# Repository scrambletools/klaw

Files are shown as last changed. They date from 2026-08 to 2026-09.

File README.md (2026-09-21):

# KLAW - 34-key split keyboard

KLAW is a compact **34-key split keyboard with LEDs, OLED, buzzer and
encoder**. It is designed as one reversible PCB that serves both halves -
components on the back face make the right half, components on the front face
make the left half. One board design: the same gerber files can be used for
both halves, with separate BOM and CPL files per half. Every component can be
machine-assembled, but you may want to hand-assemble the MCU and OLED modules.
The latest hardware revision is rev 2.

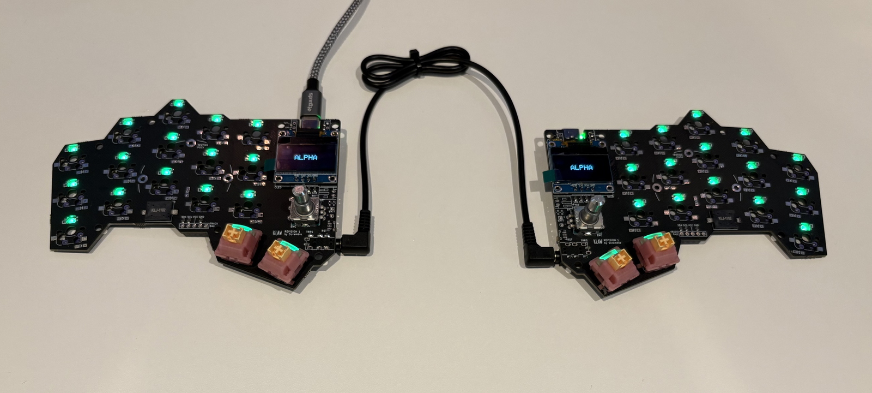
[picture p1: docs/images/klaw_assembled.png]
KLAW - assembled pair


Below are renders of the right half:

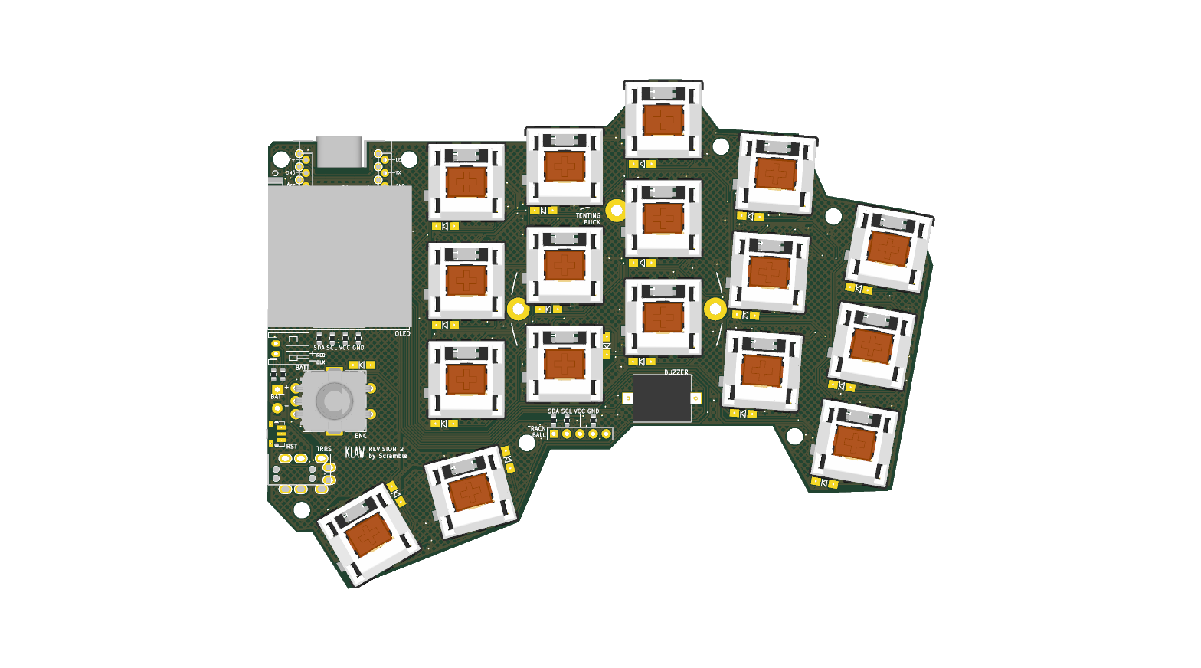
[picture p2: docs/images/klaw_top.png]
KLAW PCB - keycap side

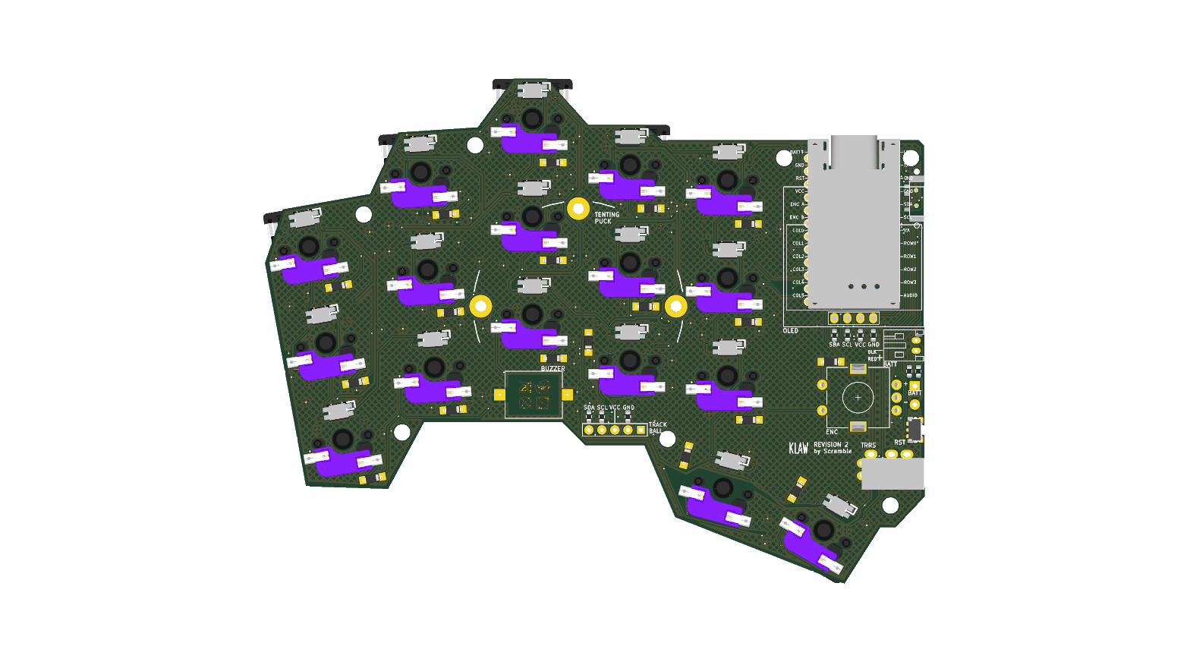
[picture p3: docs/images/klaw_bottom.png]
KLAW PCB - component side


## Features

- **34 keys** (17 per half), column-staggered, MX-style switches
- **Hot-swap sockets** (Kailh CPG151101S11-compatible) - no switch soldering
- **Per-key RGB** - SK6812MINI-EA LEDs, reverse-mounted to glow through the board (machine-assemblable)
- **Wired or wireless** - TRRS between halves, or Bluetooth with a
  nice!nano-compatible controller (socketed, Pro Micro pinout); battery
  connector and power switch on board (unpopulated in the wired-first default)
- **Rotary encoder** (EC11) per half - volume knob or anything you map to it
- **0.96″ SSD1306 OLED** per half
- **Piezo buzzer**, reset button, and optional
  [splitkb tenting puck](https://splitkb.com/products/tenting-puck) mounting
- **Optional trackball** level-converter header (unpopulated by default)
- **Configuration by placement** - the OLED mapping, trackball routing, and
  battery-polarity links are 0603 0R resistors, placed per side by the
  assembly service; nothing to bridge by hand

## Repository layout

| Path | Contents |
|---|---|
| `pcb/klaw_2/` | KiCad 10 project - schematic, board, project library with LCSC sourcing fields and 3D models |
| `fab/` | JLCPCB production files - gerbers, drills, BOM, placement (see `fab/README.md`) |
| `bom/` | Per-half build BOMs (`bom_left.csv`, `bom_right.csv`) with LCSC part numbers |
| - | Firmware (QMK/Vial) lives in [scrambletools/klaw-firmware](https://github.com/scrambletools/klaw-firmware) |

The case is designed in Plasticity and maintained outside this repository.

## Building one

**1. Order the PCBs.** Both halves use the **same board** - upload
`fab/klaw_2-gerbers.zip` to [JLCPCB](https://jlcpcb.com) (2-layer, 1.6 mm). For
machine assembly place **two orders with the same gerbers**: the right half
assembles on the **Bottom** side (`fab/right-half/`), the left half on the
**Top** side (`fab/left-half/`). Each order is double-sided and covers everything
solderable - see `fab/README.md` for the exact flow and placement-review checklist.

**2. No soldering required** - the assembly orders cover everything solderable:
diodes, factory-reversed per-key RGB LEDs (SK6812MINI-EA), hot-swap sockets,
TRRS, buzzer, reset switch, encoder, and each side's 0R configuration resistors
(double-sided assembly: the buzzer and encoder mount on the keycap face, every
other machine-placed part on the component face).
Mount-face tables, part numbers, prices, and per-half quantities are in `bom/`.

**3. Add your own** MX-style switches (hot-swap, no soldering), a
nice!nano-compatible controller (socket it - the MCU mounts on the **bottom**,
components facing the PCB, as marked on the silkscreen), a 4-pin I²C SSD1306
OLED module, and keycaps. For a wireless build, additionally fit the power
switch (`C431540`), JST battery connector (`C173752`), and a 301230-or-similar
LiPo - those three positions are DNP in the wired-first default, but their
polarity-selection resistors are already placed correctly per side.

**4. Firmware.** Flash the KLAW firmware (QMK/Vial) from
[scrambletools/klaw-firmware](https://github.com/scrambletools/klaw-firmware).

The KiCad project embeds datasheet links, LCSC part numbers, and last-checked
stock/pricing on every schematic symbol, so `kicad-cli sch export bom` always
gives you a current shopping list.

## Credits & license

KLAW is a derivative of the [KLOR](https://github.com/GEIGEIGEIST/KLOR)
keyboard by GEIGEIGEIST - the layout, reversible-footprint approach, and much
of the PCB heritage come from that project. Licensed under **GPL-3.0**, same
as KLOR; see `LICENSE.md`. The Cherry MX switch 3D model comes from the
[kiswitch keyswitch-kicad-library](https://github.com/kiswitch/keyswitch-kicad-library)
(MIT / CC-BY-SA 4.0); the nRF52840 SuperMini controller model comes from
[shnaps/garden36](https://github.com/shnaps/garden36) (MIT).

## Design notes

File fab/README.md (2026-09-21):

# KLAW - Fabrication & Assembly Files

Production files for **JLCPCB** (PCB fab + PCBA assembly). One reversible board
serves both keyboard halves - same gerbers, two assembly configurations:

- **Right half** = keycap side is the PCB **front**; machine-assembled parts go
  on the **Bottom** (back) face
- **Left half** = mirror image; machine-assembled parts go on the **Top**
  (front) face

- **Board size:** ~128 × 97 mm
- **Layers:** 2 (F.Cu / B.Cu), 1.6 mm
- **Assembly per board:** 8 BOM line items, 65 placements, **double-sided**
  (JLC Standard assembly). Component face: 18 diodes, 17 reverse-mount
  SK6812MINI-EA LEDs, 17 hotswap sockets, TRRS jack, reset switch. Keycap
  face: buzzer, encoder.
- **Not assembled:** power switch + JST connector (DNP, wired-first config),
  MCU + OLED (user-supplied, socketed), MX switches + keycaps (plug-in).
  Nothing on the board needs a soldering iron after assembly.
- **Orientation:** the component face is the keyboard's underside - mostly
  Bottom for the right-half order, mostly Top for the left-half (each order is
  double-sided). Backwards-looking bottom silkscreen text in the raw 2D gerber
  view is correct (viewer convention), and Bottom-layer parts (e.g. the right
  build's diodes) legitimately look mirrored/reversed when compared against a
  top view - judge polarity only by comparing a part against the silkscreen
  arrow in the SAME view, never across views. The two builds' rotations are
  twins by construction (shared-pad parts: bottom = (540 - top) mod 360).
- LED placement rows use synthetic designators (`LED1`…`LED21`, numbered by key)
  since the LEDs share footprints with the switches; JLCPCB matches them by
  coordinates. The LED bodies protrude ~0.2 mm past the far face - JLC may add
  an assembly-fixture charge for this.

> These files are committed from the design in `../pcb/klaw_2/`; don't hand-edit
> them. Regenerate with `kicad-cli` after design changes.

## How to order a pair

Place **two PCBA orders**, both using the **same** `klaw_2-gerbers.zip`:

| Order | Gerbers | BOM | CPL | Assembly side |
|---|---|---|---|---|
| Right halves | `klaw_2-gerbers.zip` | `right-half/klaw_2-right-BOM.csv` | `right-half/klaw_2-right-CPL.csv` | both (mostly Bottom) |
| Left halves | `klaw_2-gerbers.zip` | `left-half/klaw_2-left-BOM.csv` | `left-half/klaw_2-left-CPL.csv` | both (mostly Top) |

JLCPCB's minimum order is 5 boards / 2 assembled, so a typical pair order is:
2× assembled right + 2× assembled left, with spare bare boards left over.

> **Check the placement preview.** Rotation conventions vary between tools, so
> in JLCPCB's "parts placement" review verify each part sits on its pads -
> diode polarity against the silkscreen arrows - and nudge rotations there if
> needed. JLC's DFM review also flags misalignments. **Exception - LEDs:** the
> preview renders from JLC's library model, which is 180° off from the OPSCO
> datasheet for C5378731, so correctly-ordered LEDs will LOOK 180° rotated in
> the preview. Do NOT "fix" them there; verify with the bare-board diode test
> on arrival instead (see postmortem below).
> Known rotation rules baked into these CPLs (re-apply if regenerating):
> hotswap sockets (HS*) **and LEDs (LED*)** carry a +180° intrinsic tape offset
> on both layers. Bottom-layer rows additionally need +180° over the naive
> (360-θ) mirror ONLY for parts whose footprint has shared/same pads on both
> faces (diodes, TRRS, encoder); parts with per-face mirrored pad patterns
> (LEDs, sockets, buzzer, reset switch) absorb the flip in the footprint and
> use the plain mirror (plus intrinsic offset where noted). Current calibrated
> LED values: Top rows 180° (176° for the rotated key), Bottom rows 0° (4°).
>
> **Run-1 postmortem (2026-09):** both halves shipped with every LED rotated
> 180°. The footprint's original silkscreen marked the wrong pad, so the JLC
> preview calibration AND physical inspection both "confirmed" the reversed
> placement - and JLC's library model for C5378731 numbers the pins 180° from
> the OPSCO datasheet (datasheet: 1 GND, 2 DIN, 3 VDD, 4 DOUT). A reversed
> SK6812MINI-EA clamps the 5 V rail through its body diode (~0.4 V in diode
> mode, ~0.7 V under load) and the board plays dead, while ohms mode reads a
> healthy-looking ~7 kΩ (meter voltage below the junction threshold).
> **Acceptance test for every batch, bare board, before fitting a controller:**
> diode mode across VCC↔GND - **+ on VCC must read open**; ~0.4 V there means
> reversed LEDs (+ on GND showing ~0.5 V is the normal body diode). The
> silkscreen GND-pad mark is fixed as of run 2; parts must match it.

## Files

| File | Purpose |
|---|---|
| `klaw_2-gerbers.zip` | Upload to JLCPCB for PCB fab (copper, mask, paste, silk, edge, drills) - shared by both orders |
| `right-half/` | Assembly BOM + CPL for the right half (Top side) |
| `left-half/` | Assembly BOM + CPL for the left half (Bottom side) |
| `klaw_2-*.gbr`, `klaw_2-*.drl` | The individual layers inside the zip, for inspection |

## Ordering notes

- **Wired-first configuration:** the power switch (PSW1) and JST battery
  connector (BT1) are DNP - the wireless parts return in a future battery
  variant.
- LED (`LED1`…) and socket (`HS1`…) placement rows use synthetic designators -
  they share footprints with the switches; JLCPCB matches by coordinates.
- The 0R configuration resistors (`JP*`) select each build's configuration: each
  order places only its build's subset (keycap-face OLED/trackball set +
  component-face JST-polarity pair), so OLED pin mapping and battery polarity
  are correct per side with no hand bridging. Do NOT add the other side's JP
  rows to an order - the JST pairs are mutually exclusive.
- Confirm C41430893 (sockets) and the THT parts exist in JLCPCB's parts library
  at order time, or pre-order them into your JLC parts account.
- The buzzer (`C201047`) runs low on stock; check availability before ordering.

## Regenerating

```sh
cd pcb/klaw_2
kicad-cli pcb export gerbers -o ../../fab/ \
  --layers F.Cu,B.Cu,F.Mask,B.Mask,F.Paste,B.Paste,F.Silkscreen,B.Silkscreen,Edge.Cuts \
  --no-protel-ext klaw_2.kicad_pcb
kicad-cli pcb export drill --excellon-separate-th -o ../../fab/ klaw_2.kicad_pcb
kicad-cli pcb export pos --format csv --units mm --side both -o pos.csv klaw_2.kicad_pcb
# right CPL: Assembly=JLC refs, Layer=Top, as exported
# left CPL:  same refs/coords, Layer=Bottom, rotation = (360 - rot) % 360
```

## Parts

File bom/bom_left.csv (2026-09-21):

Part | Designators | Qty | LCSC Part # | Source | Mount Face | Notes
klaw reversible PCB (klaw_2) | PCB | 1 | - | JLCPCB fab | - | Same gerbers both halves; left build components on FRONT face, right build on BACK face
1N4148W diode SOD-123 | D1-D10,D12-D16,D18,D20,D21 | 18 | C81598 | LCSC/JLC-assembled | Front | Orientation per silkscreen arrow; through-plated pads
SK6812MINI-EA RGB LED (reverse-mount) | SW1-SW10,SW12-SW16,SW20,SW21 | 17 | C5378731 | LCSC/JLC-assembled | Front | Factory-reversed butterfly legs; lens shines through to keycap side
MX hotswap socket (Kailh CPG151101S11 compat) | SW1-SW10,SW12-SW16,SW20,SW21 | 17 | C41430893 | LCSC/JLC-assembled | Front | JLC-assembled; HanElectricity clone, footprint-identical to Kailh
MSK12C02 power slide switch | PSW1 | 0 | C431540 | DNP (wired config) | Front | Re-enable for battery variant; component side (opposite encoder)
Alps SKRTLAE010 reset switch | RSW1 | 1 | C110293 | LCSC | Front | JLC-assembled on component side (opposite encoder); side-actuated at board edge
JST PH 2-pin battery connector (S2B-PH-K-S) | BT1 | 0 | C173752 | DNP (wired config) | Front | Re-enable for battery variant; mounts on component side
TRRS jack PJ-320A-4P (MJ-4PP-9 compatible THT) | J1 | 1 | C18185602 | LCSC | Front | JLC-assembled on component side; body sits 1.75mm off-center vs keycap-face mount - check case aperture; verify slot fit on first order
Piezo buzzer KLJ-1102 | BZ1 | 1 | C201047 | LCSC | Back | HAND-SOLDER on keycap side; AST1109MLTRQ is a drop-in substitute; low stock
EC11 rotary encoder w/ switch (Alps EC11N1525404) | SW18 | 1 | C470748 | LCSC | Back | HAND-SOLDER from keycap side; 20mm D-cut shaft - D-bore push-on or set-screw knob; 30 det/15 pulse
SSD1306 128x64 OLED module 0.96in 4-pin I2C | OLED1 | 1 | - | User-supplied | Back | Keycap side, covers MCU pins; tape the back
Controller nice!nano-compatible (nRF52840, Pro Micro pinout) | U1 | 1 | - | User-supplied | Front | Socketed on component side, components facing PCB
MX switches | SW1-SW21 keys | 17 | - | User-supplied | Back | Insert from keycap side into sockets
0R configuration resistor 0603 | JP5-JP8,JP19-JP21,JP22,JP24 | 9 | C21189 | LCSC/JLC-assembled | mixed (see fab CPL) | Replaces solder jumpers; per-side subset sets OLED mapping + JST polarity; other side's set stays empty
Trackball level converter | J3 | 0 | - | DNP | - | Marked DNP in schematic

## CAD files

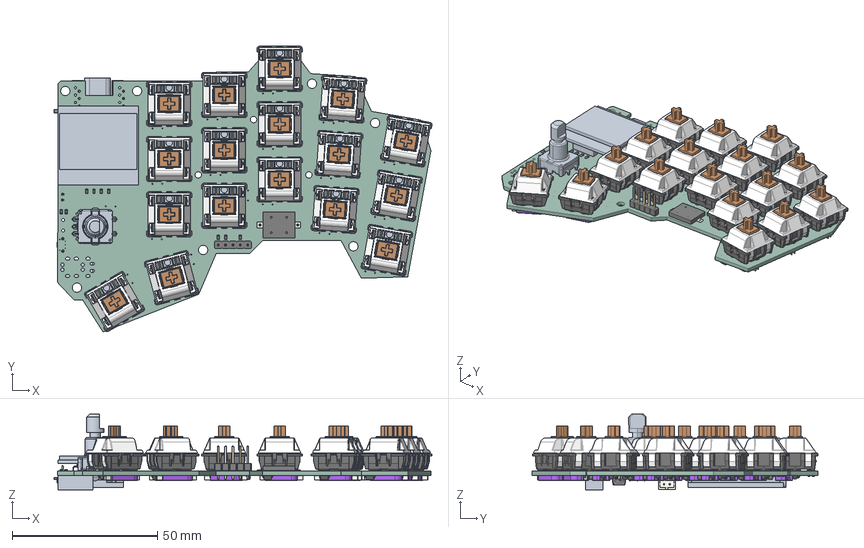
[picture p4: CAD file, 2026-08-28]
pcb/klaw_2/klaw_2.step
130.2 x 98.5 x 26.1 mm
R_0603_1608Metric x 18
SW_Cherry_MX_PCB_cp x 17
零件2 x 17
D_SOD-123 x 18
Buzzer_Mallory_AST1109MLTRQ
JST_S2B_PH_K
KEY-SMD_L4.6-W3.4-H3.4
SW-SMD_3P-L6.6-W2.7-LS7.8-P1.50
PinHeader_1x05_P254mm_Vertical
klaw_1_PCB

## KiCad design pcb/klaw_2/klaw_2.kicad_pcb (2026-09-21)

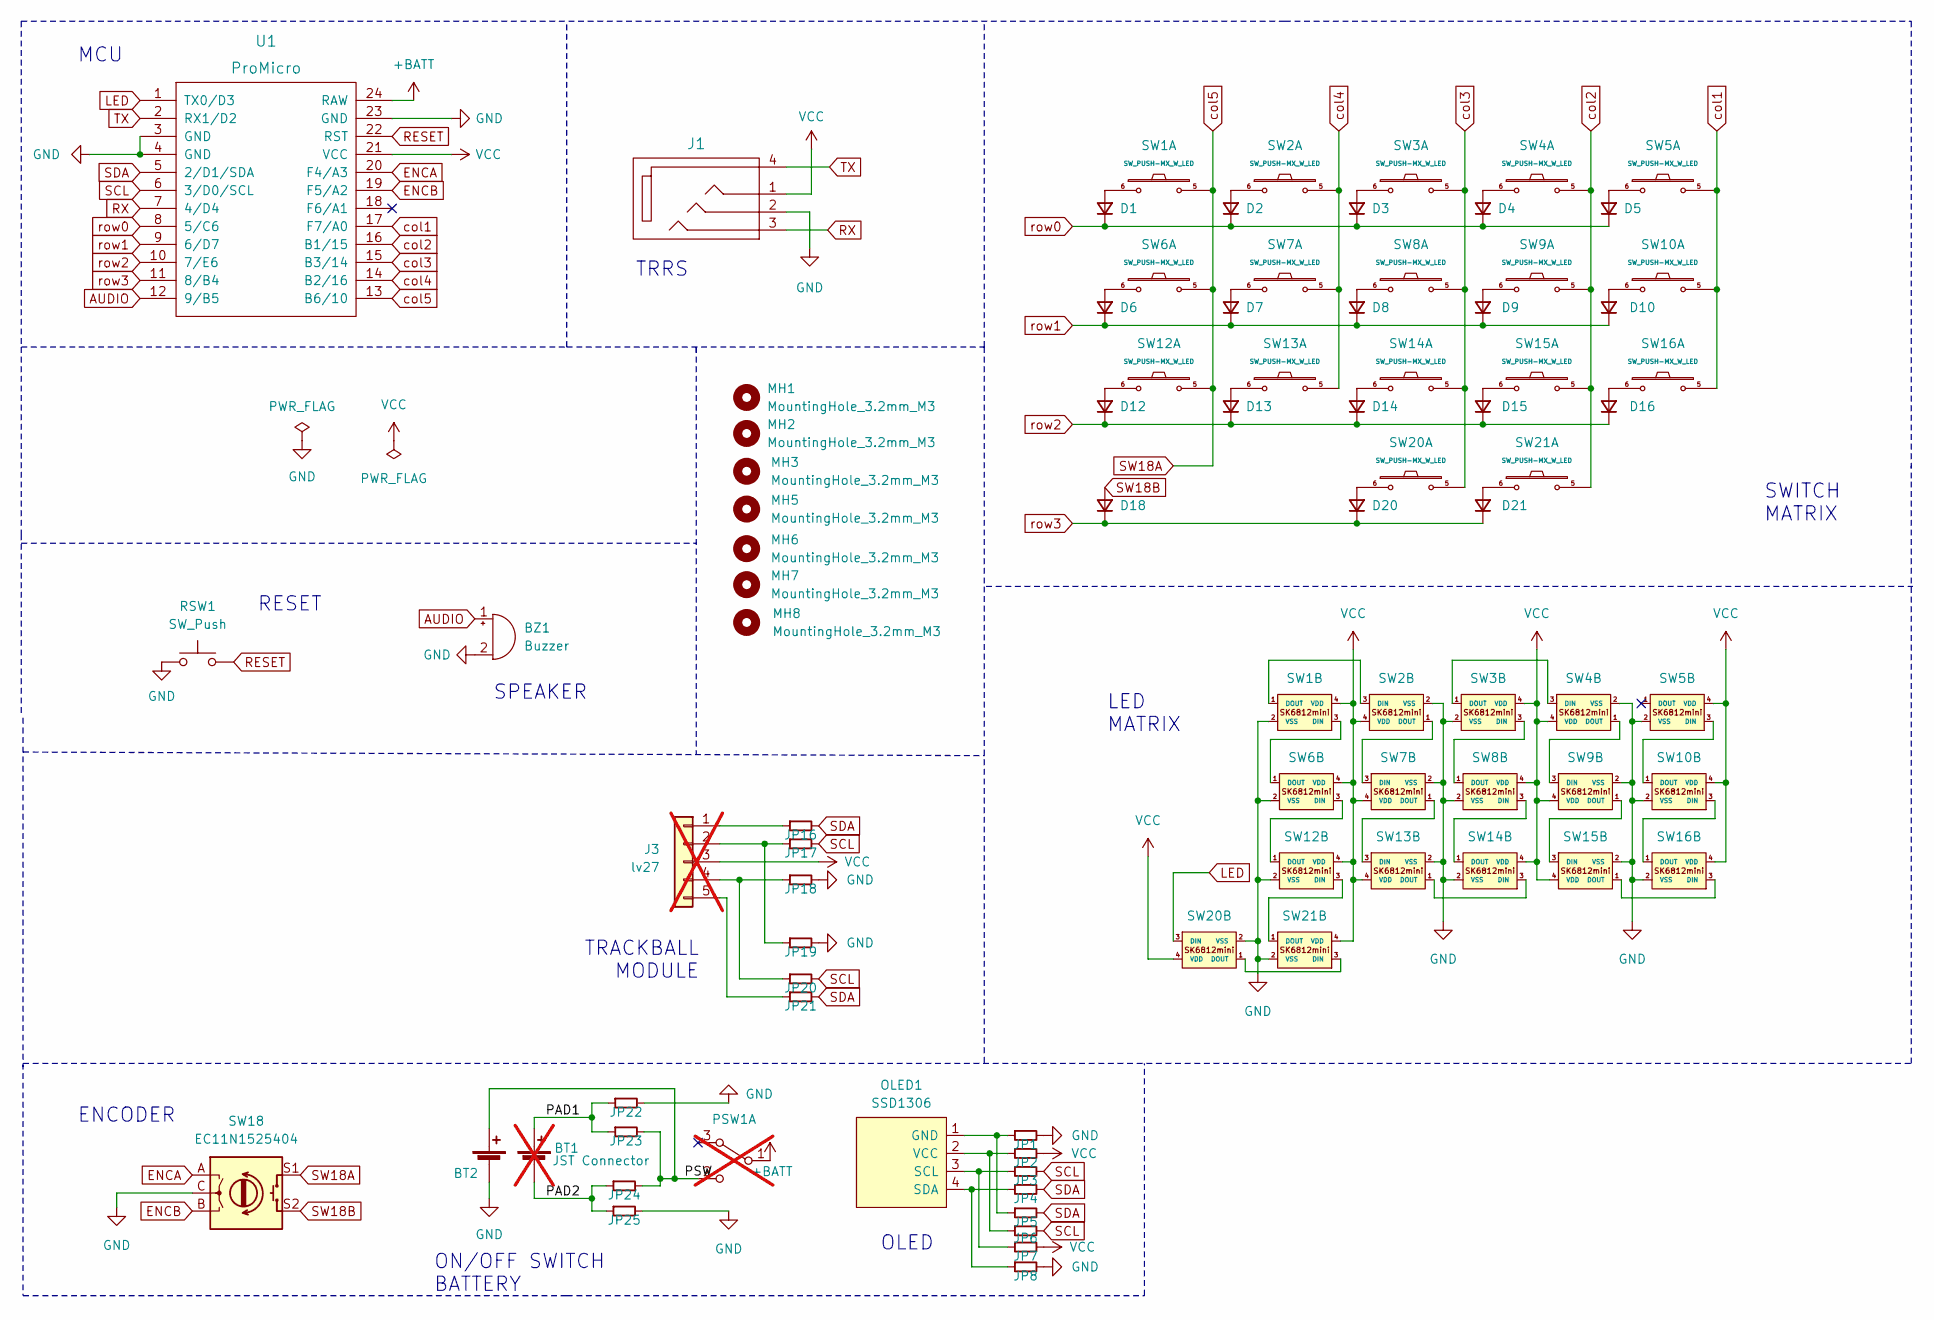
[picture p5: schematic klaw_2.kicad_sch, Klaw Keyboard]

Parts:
BT1: JST Connector; JST_PH_reversible; LCSC C173752; not fitted
BT2: Battery_Cell; custombatteryconnector_small
BZ1: Buzzer; Buzzer_Mallory_AST1109MLTRQ_reversible; LCSC C201047
D1, D2, D3, D4, D5, D6, D7, D8, D9, D10, D12, D13, D14, D15, D16, D18, D20, D21: 1N4148W; Diode_SOD123; LCSC C81598
J1: PJ-320A-4P; MJ-4PP-9; MPN PJ-320A-4P; LCSC C18185602
J3: lv27; lvc27_onlyInput; not fitted
JP1, JP2, JP3, JP4, JP5, JP6, JP7, JP8, JP16, JP17, JP18, JP19, JP20, JP21, JP22, JP23, JP24, JP25: 0R; R_0603_1608Metric; MPN 0603WAF0000T5E; LCSC C21189
MH1, MH2, MH3, MH5, MH6, MH7, MH8: MountingHole_3.2mm_M3
OLED1: SSD1306; SSD1306_128x64OLED
PSW1: SW_DPDT_x2; MSK12C02_reversible; LCSC C431540; not fitted
RSW1: SW_Push; SW_Push_1P1T-MP_NO_Horizontal_Alps_SKRTLAE010_both_sides; LCSC C110293
SW1, SW2, SW3, SW4, SW5, SW6, SW7, SW8, SW9, SW10, SW12, SW13, SW14, SW15, SW16, SW20, SW21: SW_PUSH-MX_W_LED; SK6812MINI_and_cherry; MPN SK6812MINI-EA; LCSC C5378731
SW18: EC11N1525404; RotaryEncoder_Alps_EC11E-Switch_Vertical_H20mm-keebio_modif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; MPN EC11N1525404; LCSC C470748
U1: ProMicro

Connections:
+BATT: PSW1.1 (B), U1.24 (RAW)
/PAD1: BT1.1 (+), JP22.1, JP23.1
/PAD2: BT1.2 (-), JP24.1, JP25.1
/PSW: BT2.1 (+), JP23.2, JP24.2, PSW1.2 (C)
AUDIO: BZ1.1 (-), U1.12 (9/B5)
ENCA: SW18.A, U1.20 (F4/A3)
ENCB: SW18.B, U1.19 (F5/A2)
GND: BT2.2 (-), BZ1.2 (+), J1.2, JP1.2, JP8.2, JP18.2, JP19.2, JP22.2, JP25.2, RSW1.1, SW1.2 (VSS), SW2.2 (VSS), SW3.2 (VSS), SW4.2 (VSS), SW5.2 (VSS), SW6.2 (VSS), SW7.2 (VSS), SW8.2 (VSS), SW9.2 (VSS), SW10.2 (VSS), SW12.2 (VSS), SW13.2 (VSS), SW14.2 (VSS), SW15.2 (VSS), SW16.2 (VSS), SW18.C, SW20.2 (VSS), SW21.2 (VSS), U1.3 (GND), U1.4 (GND), U1.23 (GND)
LED: SW20.3 (DIN), U1.1 (TX0/D3)
unnamed: D1.2 (A), SW1.6
unnamed: D2.2 (A), SW2.6
unnamed: D3.2 (A), SW3.6
unnamed: D4.2 (A), SW4.6
unnamed: D5.2 (A), SW5.6
unnamed: D6.2 (A), SW6.6
unnamed: D7.2 (A), SW7.6
unnamed: D8.2 (A), SW8.6
unnamed: D9.2 (A), SW9.6
unnamed: D10.2 (A), SW10.6
unnamed: D12.2 (A), SW12.6
unnamed: D13.2 (A), SW13.6
unnamed: D14.2 (A), SW14.6
unnamed: D15.2 (A), SW15.6
unnamed: D16.2 (A), SW16.6
unnamed: D20.2 (A), SW20.6
unnamed: D21.2 (A), SW21.6
unnamed: J3.1, JP16.1
unnamed: J3.2, JP17.1, JP19.1
unnamed: J3.4, JP18.1, JP20.1
unnamed: J3.5, JP21.1
unnamed: JP1.1, JP5.1, OLED1.1 (GND)
unnamed: JP3.1, JP7.1, OLED1.3 (SCL)
unnamed: JP4.1, JP8.1, OLED1.4 (SDA)
unnamed: JP2.1, JP6.1, OLED1.2 (VCC)
unnamed: SW1.3 (DIN), SW6.1 (DOUT)
unnamed: SW1.1 (DOUT), SW2.3 (DIN)
unnamed: SW2.1 (DOUT), SW7.3 (DIN)
unnamed: SW3.3 (DIN), SW8.1 (DOUT)
unnamed: SW3.1 (DOUT), SW4.3 (DIN)
unnamed: SW4.1 (DOUT), SW9.3 (DIN)
unnamed: SW10.3 (DIN), SW16.1 (DOUT)
unnamed: SW5.3 (DIN), SW10.1 (DOUT)
unnamed: SW12.3 (DIN), SW21.1 (DOUT)
unnamed: SW6.3 (DIN), SW12.1 (DOUT)
unnamed: SW7.1 (DOUT), SW13.3 (DIN)
unnamed: SW13.1 (DOUT), SW14.3 (DIN)
unnamed: SW8.3 (DIN), SW14.1 (DOUT)
unnamed: SW9.1 (DOUT), SW15.3 (DIN)
unnamed: SW15.1 (DOUT), SW16.3 (DIN)
unnamed: SW20.1 (DOUT), SW21.3 (DIN)
RESET: RSW1.2, U1.22 (RST)
RX: J1.3, U1.7 (4/D4)
SCL: JP3.2, JP6.2, JP17.2, JP20.2, U1.6 (3/D0/SCL)
SDA: JP4.2, JP5.2, JP16.2, JP21.2, U1.5 (2/D1/SDA)
SW18A: SW1.5, SW6.5, SW12.5, SW18.S1, U1.13 (B6/10)
SW18B: D18.2 (A), SW18.S2
TX: J1.4, U1.2 (RX1/D2)
VCC: J1.1, J3.3, JP2.2, JP7.2, SW1.4 (VDD), SW2.4 (VDD), SW3.4 (VDD), SW4.4 (VDD), SW5.4 (VDD), SW6.4 (VDD), SW7.4 (VDD), SW8.4 (VDD), SW9.4 (VDD), SW10.4 (VDD), SW12.4 (VDD), SW13.4 (VDD), SW14.4 (VDD), SW15.4 (VDD), SW16.4 (VDD), SW20.4 (VDD), SW21.4 (VDD), U1.21 (VCC)
col1: SW5.5, SW10.5, SW16.5, U1.17 (F7/A0)
col2: SW4.5, SW9.5, SW15.5, SW21.5, U1.16 (B1/15)
col3: SW3.5, SW8.5, SW14.5, SW20.5, U1.15 (B3/14)
col4: SW2.5, SW7.5, SW13.5, U1.14 (B2/16)
row0: D1.1 (K), D2.1 (K), D3.1 (K), D4.1 (K), D5.1 (K), U1.8 (5/C6)
row1: D6.1 (K), D7.1 (K), D8.1 (K), D9.1 (K), D10.1 (K), U1.9 (6/D7)
row2: D12.1 (K), D13.1 (K), D14.1 (K), D15.1 (K), D16.1 (K), U1.10 (7/E6)
row3: D18.1 (K), D20.1 (K), D21.1 (K), U1.11 (8/B4)

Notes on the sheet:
SWITCH MATRIX
MCU
ON/OFF SWITCH BATTERY
ENCODER
OLED
LED MATRIX
TRRS
TRACKBALL MODULE
RESET
SPEAKER

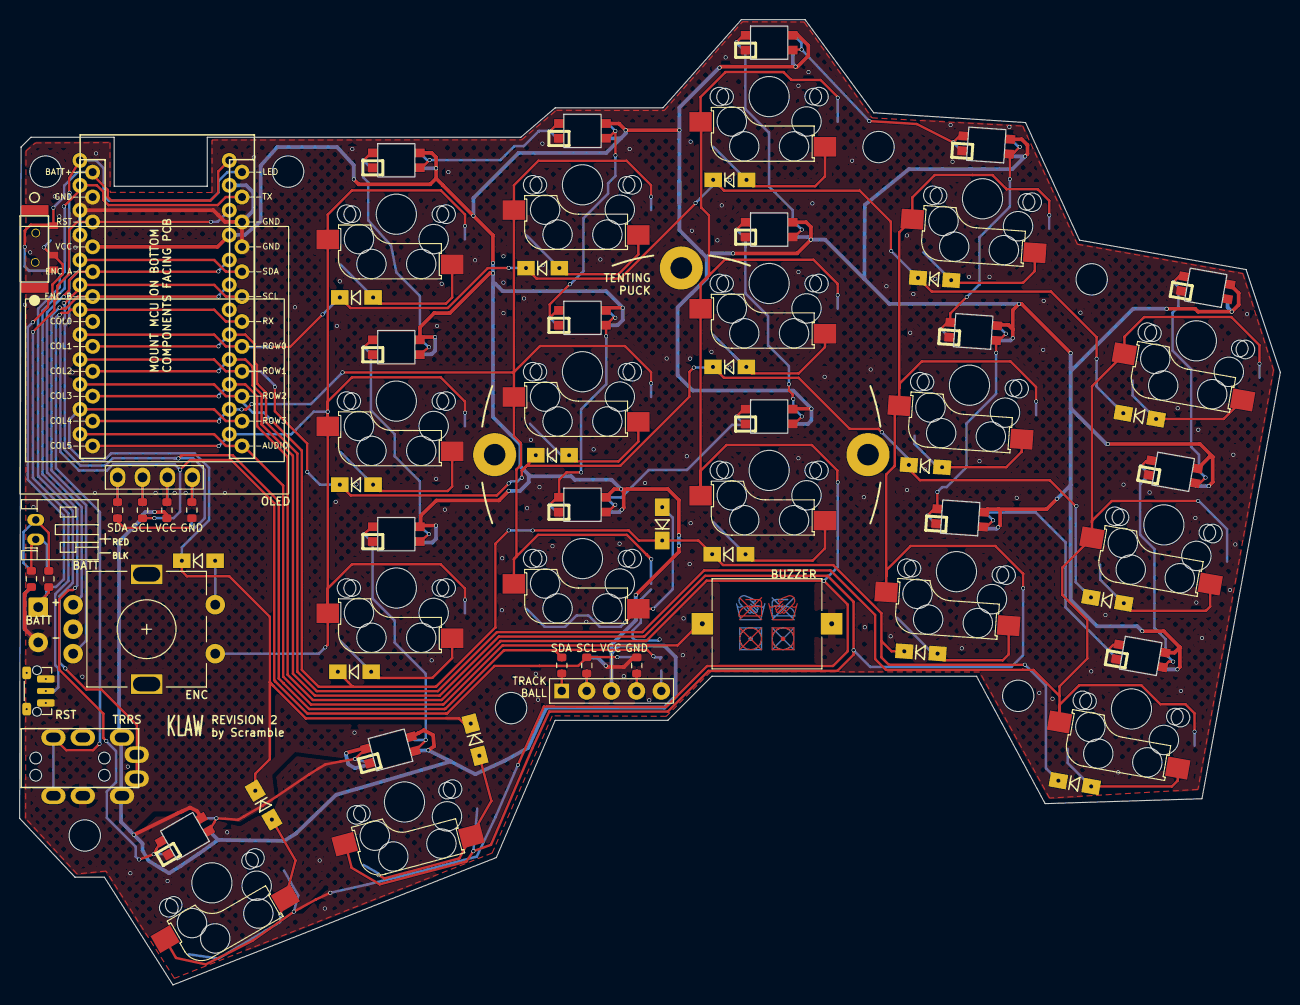
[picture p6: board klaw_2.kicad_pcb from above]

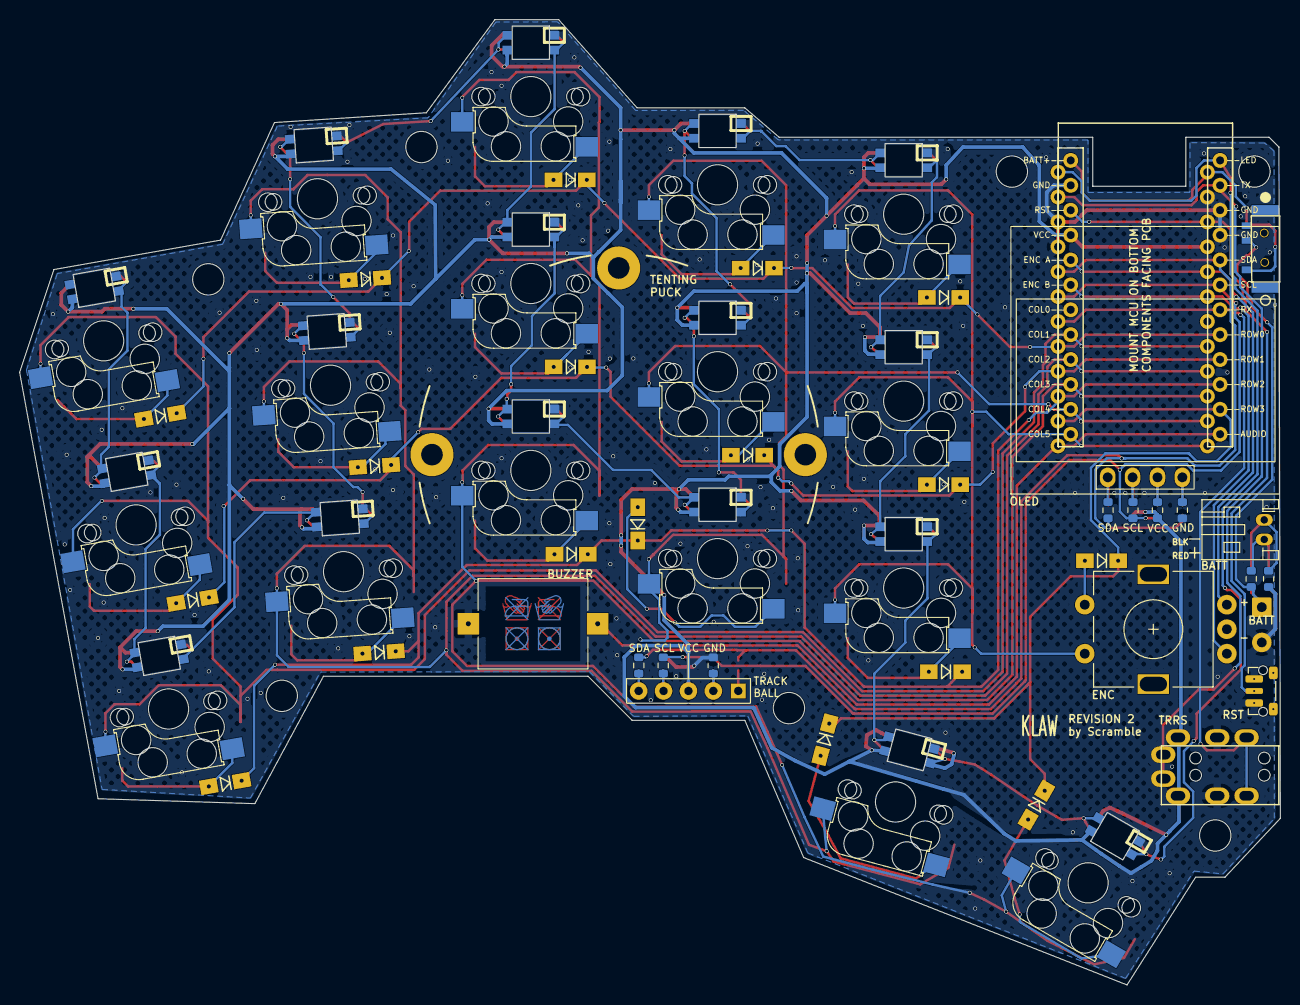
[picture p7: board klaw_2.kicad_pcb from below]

Board: 2 copper layers, 128.6 x 98.5 mm, 70 parts (9 on the bottom side), 66 nets.

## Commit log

2026-08-21 feat: initial KLAW 34-key reversible split keyboard
    - KiCad 10 project derived from GEIGEIGEIST's KLOR (GPL-3.0)
    - one reversible PCB serves both halves (front=right, back=left)
    - hot-swap MX, reverse-mount SK6812MINI per-key RGB, EC11 knob,
    SSD1306 OLED, buzzer, wired TRRS or nice!nano wireless
    - project symbol/footprint library with LCSC sourcing fields and
    STEP models for every part
    - JLCPCB fab outputs: gerbers, drills, assembly BOM and CPL
    - per-half build BOMs with LCSC part numbers
    [bom_left.csv, bom_right.csv, klaw_1-BOM.csv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]
2026-08-21 feat: per-side JLCPCB assembly packages
    - fab/right-half/: BOM + CPL for top-side assembly (right half)
    - fab/left-half/: same parts mirrored to bottom side (left half)
    - both orders share one gerber set; README documents the two-order
    flow and the placement-review checklist for bottom-side rotations
    [klaw_1-left-BOM.csv, klaw_1-right-BOM.csv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]
2026-08-22 feat: rev 2 - machine-assemblable LEDs (SK6812MINI-EA)
    - LED footprint reworked for SK6812MINI-EA: 3.8x3.4 window per
    datasheet, EA land pattern, per-face pin maps chosen to preserve
    LED chain routing (F side rotated 180)
    - LED chain start jumper JP26 removed; LED net routed directly
    - sourcing swapped to C5378731 with MPN fields; LEDs marked as
    JLC-assembled, sockets remain hand-solder
    - fab refresh: rev-2 gerbers, LED placement rows in both CPLs
    (41 placements/side), READMEs updated
    - new EA 3D model
    [bom_left.csv, bom_right.csv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]
2026-08-22 docs: rev-2 board renders
2026-08-22 fix: encoder removed from assembly files
    - EC11 knob must face the keycap side (opposite the component face),
    so machine-placing it with the belly-side parts was wrong on both
    CPLs; it is now a hand-solder part inserted from the keycap side
    - assembly is 7 BOM lines / 40 placements per board, single-sided
    - fab README documents build orientation: populated face is the
    keyboard underside; JLC preview showing Bottom-only for the left
    order is correct
    [bom_left.csv, bom_right.csv, klaw_1-left-BOM.csv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]
2026-08-22 feat: wired-first config - PSW1 and BT1 DNP
    - power switch and JST battery connector marked DNP in schematic
    - removed from both assembly BOMs/CPLs (5 lines, 38 placements)
    - build BOMs note the wired-config DNP
    [bom_left.csv, bom_right.csv, klaw_1-left-BOM.csv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]
2026-08-22 fix: assembly files match confirmed KLOR mounting map
    - right build keycap side = PCB front, so machine assembly runs on
    the Bottom layer for right halves and Top for left (was inverted)
    - assembly reduced to component-face parts only: diodes + LEDs,
    2 BOM lines / 35 placements per side
    - TRRS, buzzer, reset join encoder as keycap-face hand-solder parts
    - per-side build BOMs rewritten with per-row mount faces
    - fab README documents orientation and silkscreen viewer convention
    [bom_left.csv, bom_right.csv, klaw_1-left-BOM.csv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]
2026-08-22 feat: full JLC assembly - double-sided orders
    - JLC assembles everything except DNP parts (PSW1, BT1) and
    user-supplied MCU/OLED; no soldering needed after assembly
    - CPLs are double-sided: component face gets diodes, LEDs, and
    hotswap sockets (synthetic HSx rows); keycap face gets TRRS,
    buzzer, reset switch, encoder — 7 BOM lines, 56 placements/side
    - Assembly fields and docs updated to match
    [bom_left.csv, bom_right.csv, klaw_1-left-BOM.csv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]
2026-08-22 fix: normalize CPL rotations to 0-360
    [klaw_1-left-CPL.csv, klaw_1-right-CPL.csv]
2026-08-22 feat: configuration jumpers become 0R resistors
    - JP1-8 (OLED), JP16-21 (trackball), JP22-25 (JST polarity) now
    0R 0603 resistors (C21189, JLC Basic) placed per side by assembly
    instead of hand-bridged solder jumpers
    - new R_0R schematic symbol, pin-compatible with the jumper symbol
    - JST polarity pairs are face-exclusive (F: JP22+JP24, B: JP23+JP25)
    so per-side placement is polarity-correct by construction
    - R_0603 footprint + 3D model added to project library
    [klaw_1.kicad_sch]
2026-08-22 feat: 0R configuration resistors in assembly
    - board rerouted for 0603 pads at former jumper positions; DRC clean
    - each order places its side's subset: keycap-face OLED/trackball
    set plus component-face JST-polarity pair (mutually exclusive
    pairs documented) - 8 BOM lines, 65 placements per side
    - ref/value hidden on the 18 resistors; fresh gerbers
    [bom_left.csv, bom_right.csv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]
2026-08-22 fix: hotswap socket CPL rotation +180 (JLC tape orientation)
    [klaw_1-left-CPL.csv, klaw_1-right-CPL.csv]
2026-08-22 fix: +180 on all Bottom-layer CPL rotations (JLC convention)
    [klaw_1-left-CPL.csv, klaw_1-right-CPL.csv]
2026-08-22 fix: bottom rotation +180 only for shared-pad parts
    - per-face-pattern parts (LEDs, sockets, buzzer, reset) absorb the
    face flip in the footprint; blanket bottom +180 reverted for them
    - shared-pad parts (diodes, TRRS, encoder) keep the +180
    - README documents the calibrated per-class rule
    [klaw_1-left-CPL.csv, klaw_1-right-CPL.csv]
2026-08-22 docs: README refresh - final assembly model and rev renders
    - correct build-to-face description (components on back = right half)
    - feature list: configuration-by-placement 0R links, wired-first note
    - build steps match the fully machine-assembled fab package
    - fresh keycap-side and component-side renders
2026-08-22 feat: accurate Cherry MX switch 3D model
    - replaces the simplified box model with SW_Cherry_MX_PCB from the
    kiswitch keyswitch-kicad-library (MIT / CC-BY-SA 4.0, credited)
    - footprint and board references updated; fresh README renders
    [klaw_1.step]
2026-08-22 feat: OLED model for direct male-header mount
    - module sits on the 2.54mm header spacer (no socket): glass top
    ~5mm above board, fits under the switchplate
    - replaces the socketed-stack model
    [klaw_1.kicad_pcb]
2026-08-22 feat: accurate nRF52840 SuperMini controller model
    - replaces the parametric box with the garden36 nRF52840 model (MIT,
    credited), baked into bottom-mount orientation: male header strips,
    components facing the PCB, USB-C at the board edge
    - mid-mount USB fits entirely within the 2.54mm header gap
    [klaw_1.kicad_pcb]
2026-08-22 feat: shorter encoder - Alps EC11N1525404
    - replaces EC11E15244G1: same exact EC11 footprint, 15mm D-cut
    shaft, 19.5mm above PCB (was 24.5mm) - matches the original KLOR
    height spec; 30 det/15 pulse, 1.5mm switch travel
    - official Alps 3D CAD model, baked to footprint orientation
    - sourcing fields, build BOMs, and fab BOMs updated (C470748)
    [bom_left.csv, bom_right.csv, klaw_1-left-BOM.csv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]
2026-08-23 wip: case-fit layout adjustments + doc render refresh
    - PSW1, U1, MH1, MH6 repositioned for the case design (in progress:
    four GND stitches and one stale track still to fix before the
    next fab refresh)
    - doc renders updated to current placements
    - stale KLOR-era gerbers removed from pcb dir (untracked)
    [klaw_1.kicad_pcb]
2026-08-23 refactor: rename KLOR* libraries to klaw*
    - KLOR.pretty -> klaw.pretty, KLOR.3dshapes -> klaw.3dshapes,
    KLORlib.kicad_sym -> klawlib.kicad_sym
    - lib nicknames, footprint ids, lib_ids, model paths, and doc
    references updated throughout; netlist verified identical and
    all footprints/symbols resolve (zero lib issues)
    - prose credits to the KLOR project unchanged
    [klaw_1.kicad_pcb, klaw_1.kicad_sch]
2026-08-23 chore: case design moved out of the repo
    - case model files removed; case/ ignored going forward
    - README notes the case is maintained externally in Plasticity
    [klaw_1.step]
2026-08-24 feat: TRRS moves to the component face (both builds)
    - opposite side from the encoder, per the KLOR BLE-guide convention;
    frees the keycap-side case profile
    - reversible footprint has dual peg positions so no board change;
    CPL rows swapped to the component-face layer with the calibrated
    shared-hole rotation rule
    - docs note the 1.75mm body offset between mount faces for the case
    aperture
    [bom_left.csv, bom_right.csv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]
2026-08-24 fix: TRRS 3D model to component face
    - flipped to the B-mount position (-1.75mm peg offset, under the
    board) matching the new mounting arrangement
2026-08-24 feat: reset and power switch move to the component face
    - RSW1 CPL rows swapped to the component-face layer (per-face-pad
    mirror rule); PSW1 is DNP so docs/model only
    - 3D models flipped for PSW1, RSW1, and BT1 (JST was already
    component-face per the BLE guide - model now matches)
    - keycap face now carries only buzzer, encoder, OLED, switches
    [bom_left.csv, bom_right.csv, klaw_1.kicad_pcb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]
2026-08-24 feat: 3D view depicts one consistent build (right-hand)
    - left-build option-resistor models hidden per instance (display
    only; CPLs/BOMs unaffected - both builds still orderable)
    - LED models flipped to the component face, completing the
    right-build depiction; remaining flips synced into the board
    - doc renders refreshed
    [klaw_1.kicad_pcb, klaw_1.step]
2026-08-24 feat: power switch rework per datasheet + board fixes; prod refresh
    - PSW1 ON-throw moved to pin 1 per MSK12C02 datasheet; shared pin
    numbering across faces makes DRC enforce the mirrored feed for
    both builds (verified: 0 unconnected, parity clean)
    - GND stitches restored after case-fit moves; stale rev-1 track
    deleted for good
    - fresh gerbers (case-fit positions, resistor silk, PSW rework);
    CPLs verified against unmoved assembly positions
    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
    [klaw_1-B_Cu.gbr, klaw_1-B_Mask.gbr, klaw_1-B_Paste.gbr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]
2026-08-28 feat: mounting holes repositioned for case fit; prod refresh
    - MH2/MH3 nudged, MH5/MH7/MH8 relocated per case design
    - DRC clean, no assembly positions changed (CPLs unaffected)
    - fresh gerbers/drills and doc renders
    [klaw_1-B_Cu.gbr, klaw_1-B_Mask.gbr, klaw_1-B_Paste.gbr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]
2026-08-30 fix: silkscreen adjustment; prod refresh
    - fresh gerbers and doc renders
    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
    [klaw_1-B_Cu.gbr, klaw_1-B_Mask.gbr, klaw_1-B_Paste.gbr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]
2026-09-16 fix: LED placement 180° + silkscreen GND mark; run-1 postmortem
    Run 1 shipped every SK6812MINI-EA rotated 180° on both halves: the
    footprint silk marked the wrong pad, so preview calibration and visual
    inspection both confirmed the reversed placement (JLC's library model is
    also 180° off the OPSCO datasheet). Reversed LEDs clamp the 5V rail at a
    body-diode drop and the board plays dead while reading healthy in ohms
    mode.
    - footprint: silkscreen GND-pad mark corrected on both faces (+ board)
    - CPLs: +180° on all LED rows (left Top 180/176, right Bottom 0/4)
    - gerbers/zip + doc renders regenerated with corrected silk
    - fab/README: rotation rules corrected, postmortem, bare-board
    diode-m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
    [klaw_1-B_Cu.gbr, klaw_1-B_Mask.gbr, klaw_1-B_Paste.gbr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]
2026-09-17 chore: rename project klaw_1 -> klaw_2 (board marked REVISION 2)
    Directory, project files, fab outputs, and all internal references
    (schematic project refs, board sheetfile refs, READMEs, gitignore,
    build BOMs) renamed to the klaw_2 prefix. Fab gerbers/drills/zip
    regenerated from the renamed board; DRC baseline-clean (4 waived
    RSW1 hole_clearance, 0 unconnected, parity OK).
    Note: klaw_2.step retains internal klaw_1 labels until next GUI
    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
    [bom_left.csv, bom_right.csv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]
2026-09-21 docs: README rework - assembled-pair photo, firmware repo link, KLOR cleanup
    - README: rewritten intro, hero photo of the assembled rev-2 pair
    (docs/images/klaw_assembled.png), firmware now points to
    scrambletools/klaw-firmware, KLOR build-guide reference replaced with
    direct mounting statement
    - KLOR references removed everywhere except the credits section
    (READMEs, build BOM notes, .gitignore, KiCad title blocks, root sheet
    name klor_claw -> klaw)
    - ASCII cleanup: em dashes and Unicode minus signs replaced with hyphens
    DRC after project-metadata edits: baseline-clean.
    [bom_left.csv, bom_right.csv, klaw_2.kicad_pcb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]
2026-09-21 docs: restore kiswitch and garden36 3D-model attributions
    Required by their licenses (MIT / CC-BY-SA 4.0) while the STEP models
    ship in pcb/klaw_2/klaw.3dshapes/.
